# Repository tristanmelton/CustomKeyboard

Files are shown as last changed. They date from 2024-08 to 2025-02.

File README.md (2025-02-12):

### Custom Keyboard and Numpad - Beryl.
I had some problems with Amethyst, namely:
- USB-Micro instead of USB-C
- Wired takes up an already-limited USB slot
- A little tall to type on
- Non-customizable key switches

So for Beryl, I'm proposing:
- USB-C with the nice!nano microcontroller. Also covers wireless with the built-in bluetooth.
- Going to use Kailh switches with low-profile to shorten the height, with hot-swap sockets.  

### Changelog
## 1/25/2025
I did some initial re-organization and copied the v1 to a v2 folder for initial setup. The MCU was replaced with a nice!nano and I'm using hot-swappable Kailh choc switches now.
Board should be laid out and everything - it's been sent off with JLCPCB.

PURCHASED:
- PCB x5 from JLCPCB
- Battery from Amazon
- Kailh hot-swappable sockets x100 from AliExpress
- nice!nano v2 x5 from AliExpress
- JST Connector from Digikey
- Sliding switch from Digikey
- Kailh Low Profile Choc Switches (red) x80 from Typeractive

I only have not ordered Keycaps yet. If you have any suggestions please let me know.

## 2/11/2025
I have updated the PCB with a silly mistake that had GND and VCC swapped on the battery. The software is complete and can be found (https://github.com/tristanmelton/cheapino-zmk-config-single-nicenano). The direct uf2 is also in the Software folder.

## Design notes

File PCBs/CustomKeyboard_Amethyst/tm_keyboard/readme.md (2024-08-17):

# tm_keyboard

tm_keyboard

*A short description of the keyboard/project*

* Keyboard Maintainer: [Tristan Melton](https://github.com/charsmud)
* Hardware Supported: *The PCBs, controllers supported*
* Hardware Availability: *Links to where you can find this hardware*

Make example for this keyboard (after setting up your build environment):

    make tm_keyboard:default

Flashing example for this keyboard:

    make tm_keyboard:default:flash

See the [build environment setup](https://docs.qmk.fm/#/getting_started_build_tools) and the [make instructions](https://docs.qmk.fm/#/getting_started_make_guide) for more information. Brand new to QMK? Start with our [Complete Newbs Guide](https://docs.qmk.fm/#/newbs).

## Bootloader

Enter the bootloader in 3 ways:

* **Bootmagic reset**: Hold down the key at (0,0) in the matrix (usually the top left key or Escape) and plug in the keyboard
* **Physical reset button**: Briefly press the button on the back of the PCB - some may have pads you must short instead
* **Keycode in layout**: Press the key mapped to `QK_BOOT` if it is available

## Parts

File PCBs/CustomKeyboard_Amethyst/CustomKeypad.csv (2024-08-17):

Reference | Value | Datasheet | Footprint | Qty | DNP
C1,C2 | 22p | ~ | Capacitor_SMD:C_0603_1608Metric | 2
C3,C4,C5,C6 | 0.1u | ~ | Capacitor_SMD:C_0603_1608Metric | 4
C7 | 4.7u | ~ | Capacitor_SMD:C_0603_1608Metric | 1
C8 | 1u | ~ | Capacitor_SMD:C_0603_1608Metric | 1
D1,D2,D3,D4,D5,D6,D7,D8,D9,D10,D11,D12,D13,D14,D15,D16,D17,D18,D19,D20,D21,D22,D23,D24,D25,D26,D31,D35,D36,D37,D38,D39,D40,D41,D42,D43,D44,D45,D46,D47,D48,D49,D50,D51,D52,D53,D54,D55,D56,D57,D58,D59,D60,D61,D62,D63,D64,D65,D66,D67,D68,D69,D70,D71,D72,D73,D74,D75,D76,D77,D78,D79,D80,D81 | D | ~ | Diode_SMD:D_0603_1608Metric | 74
J1 | USB_B_Micro | ~ | Connector_USB:USB_Micro-B_Amphenol_10118194_Horizontal | 1
R10,R11 | 10k | ~ | Resistor_SMD:R_0603_1608Metric | 2
R12,R13 | 22 | ~ | Resistor_SMD:R_0603_1608Metric | 2
SW_'1,SW_,1,SW_-1,SW_.1,SW_/1,SW_0,SW_1,SW_2,SW_3,SW_4,SW_5,SW_6,SW_7,SW_8,SW_9,SW_;1,SW_=1,SW_A1,SW_B1,SW_BACK1,SW_C1,SW_CAPS1,SW_D1,SW_E1,SW_ENTER1,SW_ESC1,SW_F1,SW_F2,SW_F3,SW_F4,SW_F5,SW_F6,SW_F7,SW_F8,SW_F9,SW_F10,SW_F11,SW_F12,SW_FKEY1,SW_G1,SW_H1,SW_I1,SW_J1,SW_K1,SW_L1,SW_LALT1,SW_LCTRL1,SW_LSHIFT1,SW_LWIN1,SW_M1,SW_N1,SW_O1,SW_P1,SW_Q1,SW_R1,SW_RALT1,SW_RC1,SW_RCTRL1,SW_RESET1,SW_RSHIFT1,SW_RWIN1,SW_S1,SW_SPACE1,SW_T1,SW_TAB1,SW_TILDE1,SW_U1,SW_V1,SW_W1,SW_X1,SW_Y1,SW_Z1,SW_[1,SW_\1,SW_]1 | SW_Push | ~ | -- mixed values -- | 75
U1 | ATmega32U4-A | http://ww1.microchip.com/downloads/en/DeviceDoc/Atmel-7766-8-bit-AVR-ATmega16U4-32U4_Datasheet.pdf | Package_QFP:TQFP-44_10x10mm_P0.8mm | 1
Y2 | Crystal_GND24 | ~ | Crystal:Crystal_SMD_SeikoEpson_FA238-4Pin_3.2x2.5mm | 1

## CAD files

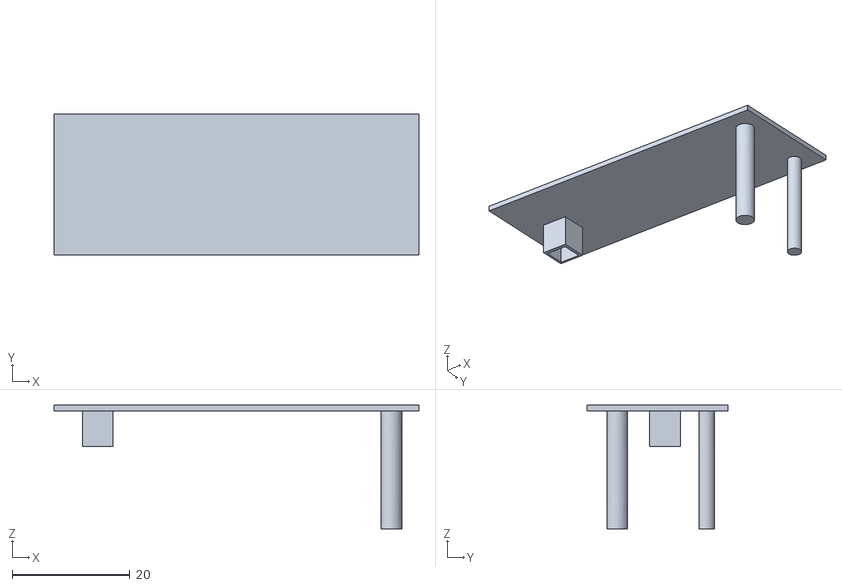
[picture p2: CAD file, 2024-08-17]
PCBs/CustomKeyboard_Amethyst/KeyHolder3.obj
62.0 x 24.0 x 21.0

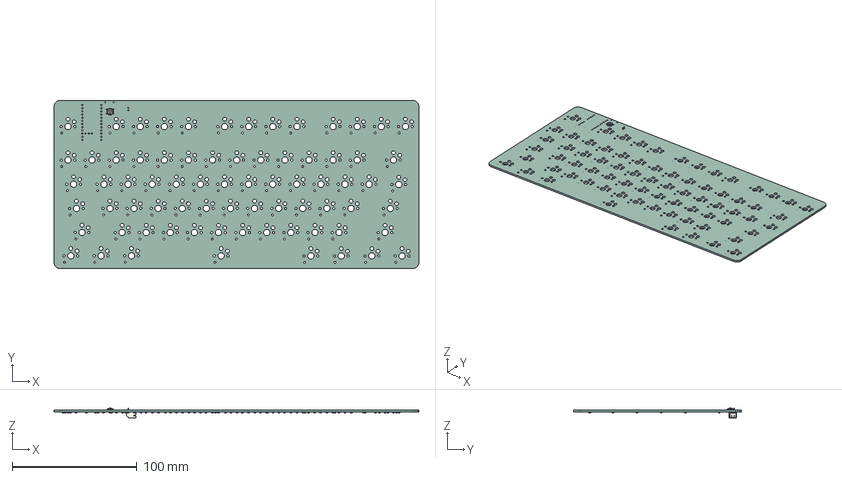
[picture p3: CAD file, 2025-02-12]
PCBs/CustomKeyboard_Beryl/CustomKeyboard.step
293.0 x 135.0 x 8.25 mm
SW_SPST_TL3342
D_0603 x 74
JST_S2B_PH_K
CustomKeyboard_PCB

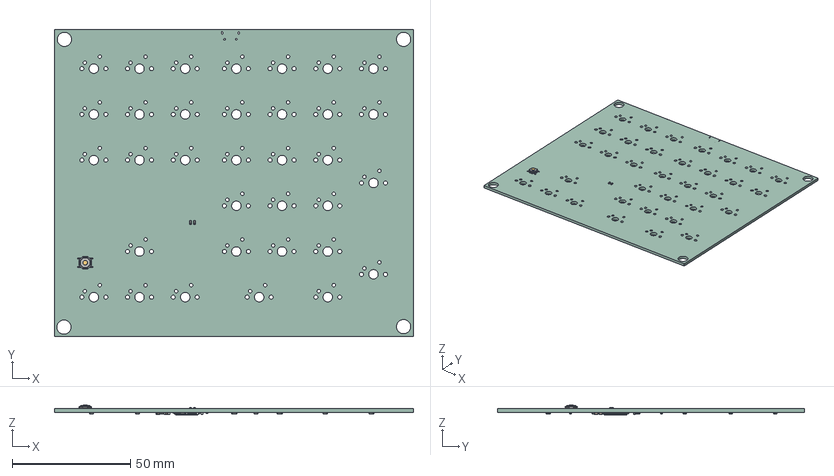
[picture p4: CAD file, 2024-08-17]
PCBs/CustomNumpad_v1/CustomNumpad.step
152.0 x 130.0 x 4.34 mm
R_0603_1608Metric x 4
SW_SPST_TL3342
D_0603 x 34
C_0603_1608Metric x 8
TQFP_44_10x10mm_P08mm
Crystal_SMD_SeikoEpson_FA238-4Pin_3.2x2.5mm
CustomNumpad_PCB

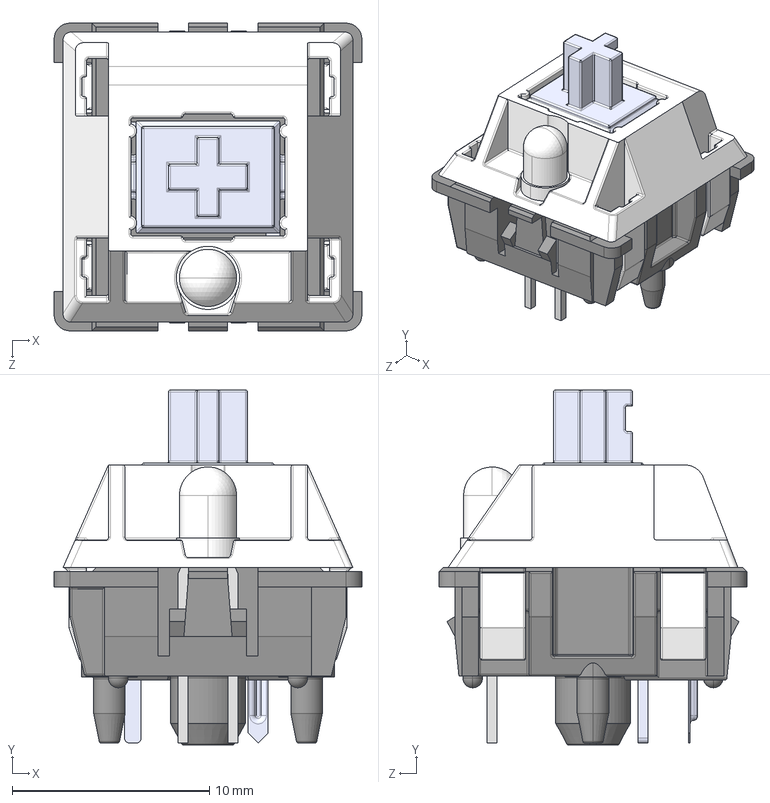
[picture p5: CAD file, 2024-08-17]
Models/Cherry MX.STEP
15.6 x 18.0 x 15.6 mm
Bottom
Pulsador
Top
Pieza5^Cherry MX
Pin1
Pin2
Led 3mm_trans

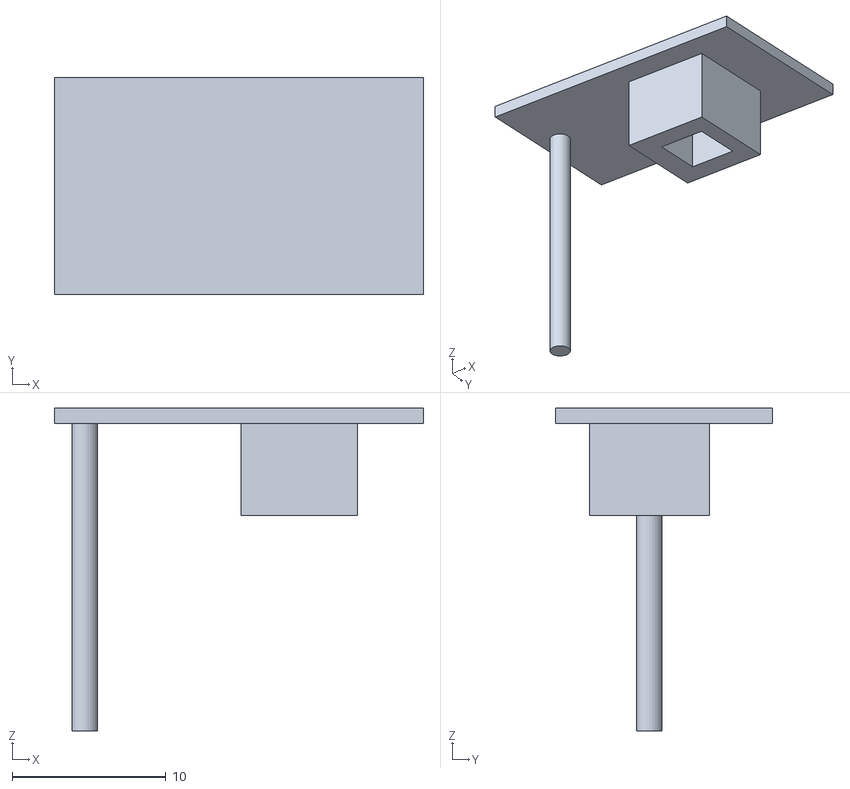
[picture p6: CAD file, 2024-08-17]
PCBs/CustomKeyboard_Amethyst/KeyHolder1.obj
24.0 x 14.1 x 21.0

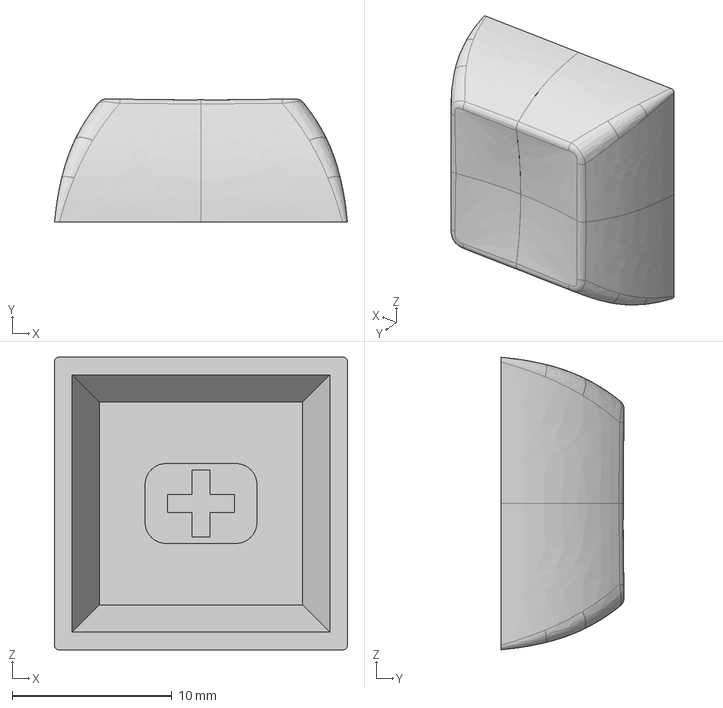
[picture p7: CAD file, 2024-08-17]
Models/DSA_Keycap_CherryMX.step
18.3 x 7.69 x 18.3 mm

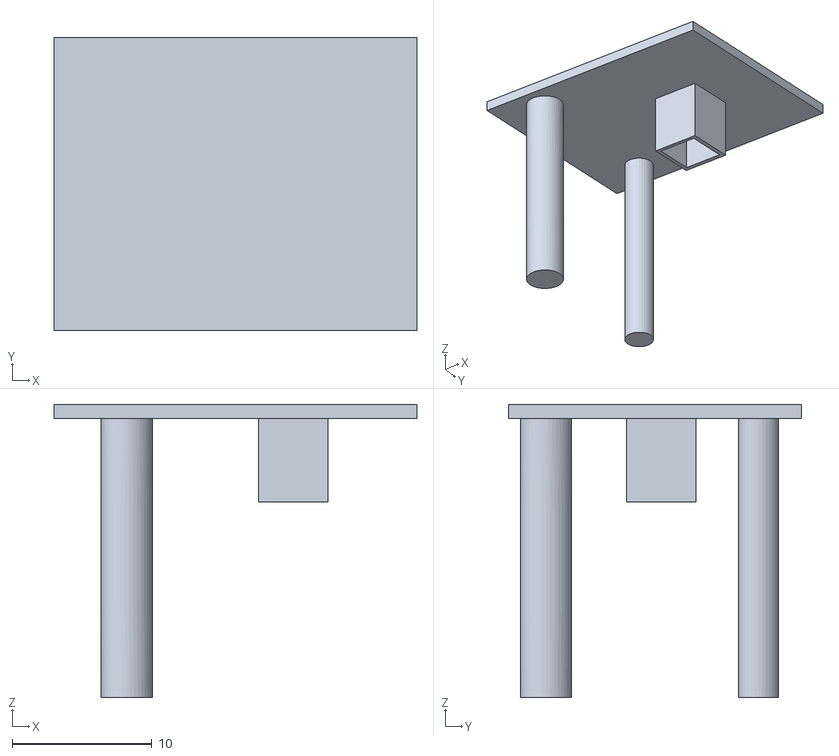
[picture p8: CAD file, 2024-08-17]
PCBs/CustomKeyboard_Amethyst/KeyHolder2.obj
26.0 x 21.0 x 21.0

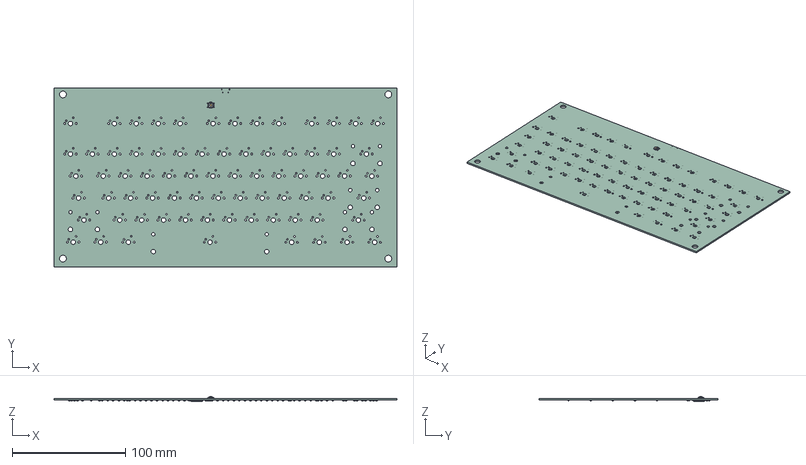
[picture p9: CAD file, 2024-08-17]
PCBs/CustomKeyboard_Amethyst/CustomKeyboard.step
302.5 x 158.3 x 4.34 mm
SW_SPST_TL3342
D_0603 x 74
C_0603_1608Metric x 8
R_0603_1608Metric x 4
TQFP_44_10x10mm_P08mm
Crystal_SMD_SeikoEpson_FA238-4Pin_3.2x2.5mm
CustomKeyboard_PCB

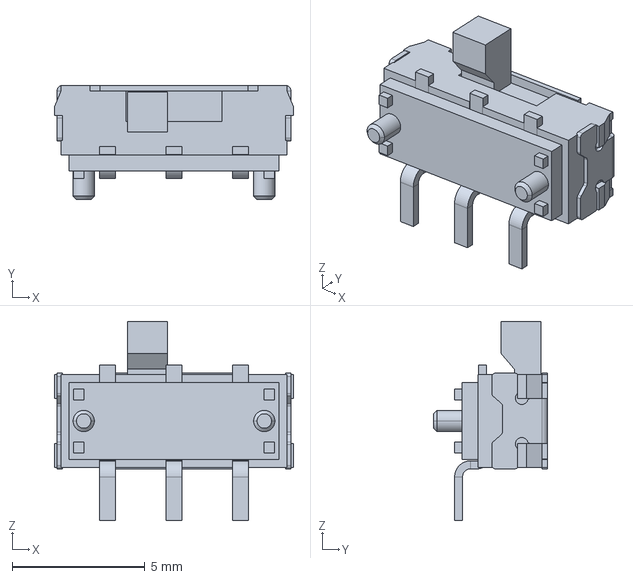
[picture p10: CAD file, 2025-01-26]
Footprints/JS102011SAQN/JS102011SAQN.step
9.00 x 4.30 x 7.50 mm

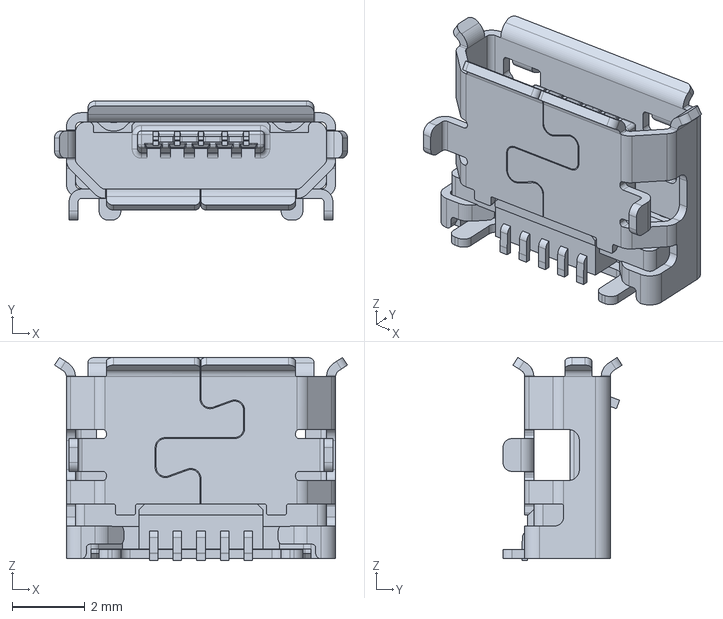
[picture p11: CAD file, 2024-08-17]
Models/10118194c.stp
8.05 x 3.27 x 5.58 mm

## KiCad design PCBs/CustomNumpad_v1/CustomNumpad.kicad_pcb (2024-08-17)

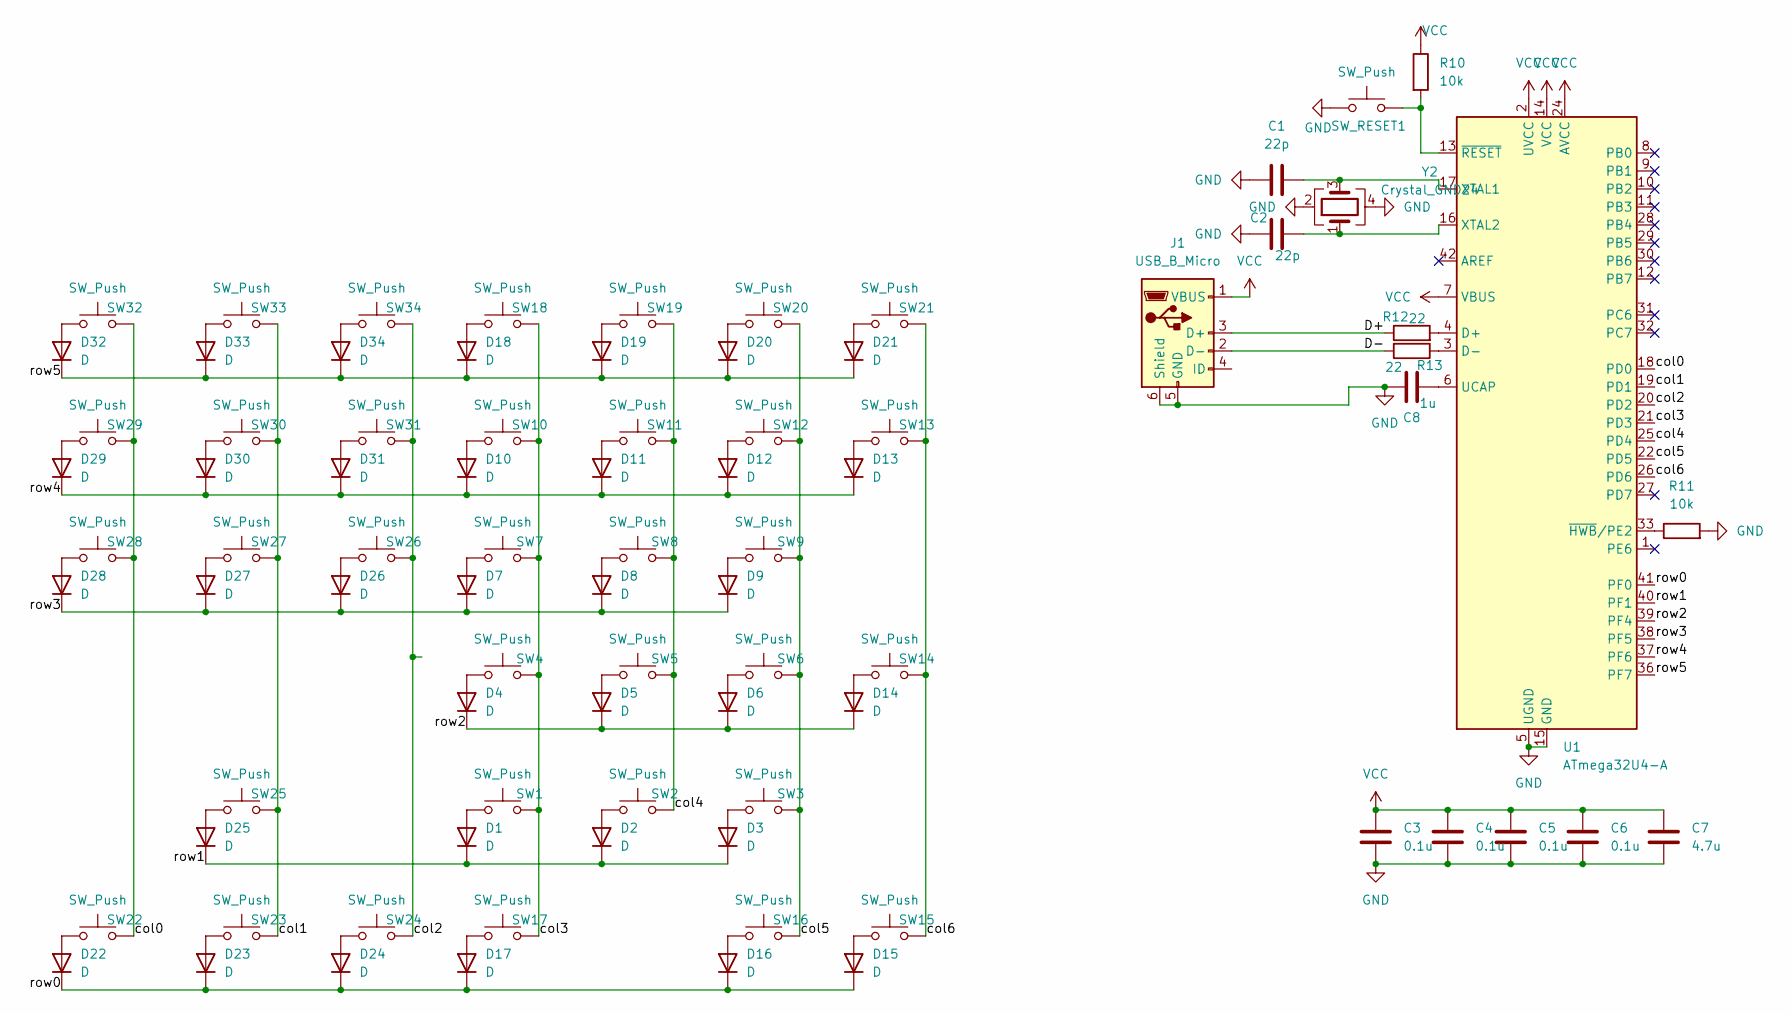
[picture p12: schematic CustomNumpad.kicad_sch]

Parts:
C1, C2: 22p; C_0603_1608Metric
C3, C4, C5, C6: 0.1u; C_0603_1608Metric
C7: 4.7u; C_0603_1608Metric
C8: 1u; C_0603_1608Metric
D1, D2, D3, D4, D5, D6, D7, D8, D9, D10, D11, D12, D13, D14, D15, D16, D17, D18, D19, D20, D21, D22, D23, D24, D25, D26, D27, D28, D29, D30, D31, D32, D33, D34: D; D_0603_1608Metric
J1: USB_B_Micro; USB_Micro-B_Amphenol_10118194_Horizontal
R10, R11: 10k; R_0603_1608Metric
R12, R13: 22; R_0603_1608Metric
SW1, SW2, SW3, SW4, SW5, SW6, SW7, SW8, SW9, SW10, SW11, SW12, SW13, SW16, SW18, SW19, SW20, SW21, SW22, SW23, SW24, SW25, SW26, SW27, SW28, SW29, SW30, SW31, SW32, SW33, SW34: SW_Push; SW_Cherry_MX_PCB_1.00u
SW14, SW15: SW_Push; SW_Cherry_MX_PCB_2.00u_90deg
SW17: SW_Push; SW_Cherry_MX_PCB_2.00u
SW_RESET1: SW_Push; SW_SPST_TL3342
U1: ATmega32U4-A; TQFP-44_10x10mm_P0.8mm
Y2: Crystal_GND24; Crystal_SMD_SeikoEpson_FA238-4Pin_3.2x2.5mm

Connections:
/D+: J1.3 (D+), R12.1
/D-: J1.2 (D-), R13.2
/col0: SW22.2, SW28.2, SW29.2, SW32.2, U1.18 (PD0)
/col1: SW23.2, SW25.2, SW27.2, SW30.2, SW33.2, U1.19 (PD1)
/col2: SW24.2, SW26.2, SW31.2, SW34.2, U1.20 (PD2)
/col3: SW1.2, SW4.2, SW7.2, SW10.2, SW17.2, SW18.2, U1.21 (PD3)
/col4: SW2.2, SW5.2, SW8.2, SW11.2, SW19.2, U1.25 (PD4)
/col5: SW3.2, SW6.2, SW9.2, SW12.2, SW16.2, SW20.2, U1.22 (PD5)
/col6: SW13.2, SW14.2, SW15.2, SW21.2, U1.26 (PD6)
/row0: D15.1 (K), D16.1 (K), D17.1 (K), D22.1 (K), D23.1 (K), D24.1 (K), U1.41 (PF0)
/row1: D1.1 (K), D2.1 (K), D3.1 (K), D25.1 (K), U1.40 (PF1)
/row2: D4.1 (K), D5.1 (K), D6.1 (K), D14.1 (K), U1.39 (PF4)
/row3: D7.1 (K), D8.1 (K), D9.1 (K), D26.1 (K), D27.1 (K), D28.1 (K), U1.38 (PF5)
/row4: D10.1 (K), D11.1 (K), D12.1 (K), D13.1 (K), D29.1 (K), D30.1 (K), D31.1 (K), U1.37 (PF6)
/row5: D18.1 (K), D19.1 (K), D20.1 (K), D21.1 (K), D32.1 (K), D33.1 (K), D34.1 (K), U1.36 (PF7)
GND: C1.1, C2.1, C3.2, C4.2, C5.2, C6.2, C7.2, C8.1, J1.5 (GND), J1.6 (Shield), R11.2, SW_RESET1.1, U1.5 (UGND), U1.15 (GND), U1.23 (GND), U1.35 (GND), U1.43 (GND), Y2.2, Y2.4
unnamed: D1.2 (A), SW1.1
unnamed: D2.2 (A), SW2.1
unnamed: D3.2 (A), SW3.1
unnamed: D4.2 (A), SW4.1
unnamed: D5.2 (A), SW5.1
unnamed: D6.2 (A), SW6.1
unnamed: D7.2 (A), SW7.1
unnamed: D8.2 (A), SW8.1
unnamed: D9.2 (A), SW9.1
unnamed: D10.2 (A), SW10.1
unnamed: D11.2 (A), SW11.1
unnamed: D12.2 (A), SW12.1
unnamed: D13.2 (A), SW13.1
unnamed: D14.2 (A), SW14.1
unnamed: D15.2 (A), SW15.1
unnamed: D16.2 (A), SW16.1
unnamed: D17.2 (A), SW17.1
unnamed: D18.2 (A), SW18.1
unnamed: D19.2 (A), SW19.1
unnamed: D20.2 (A), SW20.1
unnamed: D21.2 (A), SW21.1
unnamed: D22.2 (A), SW22.1
unnamed: D23.2 (A), SW23.1
unnamed: D24.2 (A), SW24.1
unnamed: D25.2 (A), SW25.1
unnamed: D26.2 (A), SW26.1
unnamed: D27.2 (A), SW27.1
unnamed: D28.2 (A), SW28.1
unnamed: D29.2 (A), SW29.1
unnamed: D30.2 (A), SW30.1
unnamed: D31.2 (A), SW31.1
unnamed: D32.2 (A), SW32.1
unnamed: D33.2 (A), SW33.1
unnamed: D34.2 (A), SW34.1
unnamed: R12.2, U1.4 (D+)
unnamed: R13.1, U1.3 (D-)
unnamed: C8.2, U1.6 (UCAP)
unnamed: C1.2, U1.17 (XTAL1), Y2.3
unnamed: C2.2, U1.16 (XTAL2), Y2.1
unnamed: R11.1, U1.33 (~HWB/PE2)
unnamed: R10.2, SW_RESET1.2, U1.13 (~RESET)
VCC: C3.1, C4.1, C5.1, C6.1, C7.1, J1.1 (VBUS), R10.1, U1.2 (UVCC), U1.7 (VBUS), U1.14 (VCC), U1.24 (AVCC), U1.34 (VCC), U1.44 (AVCC)

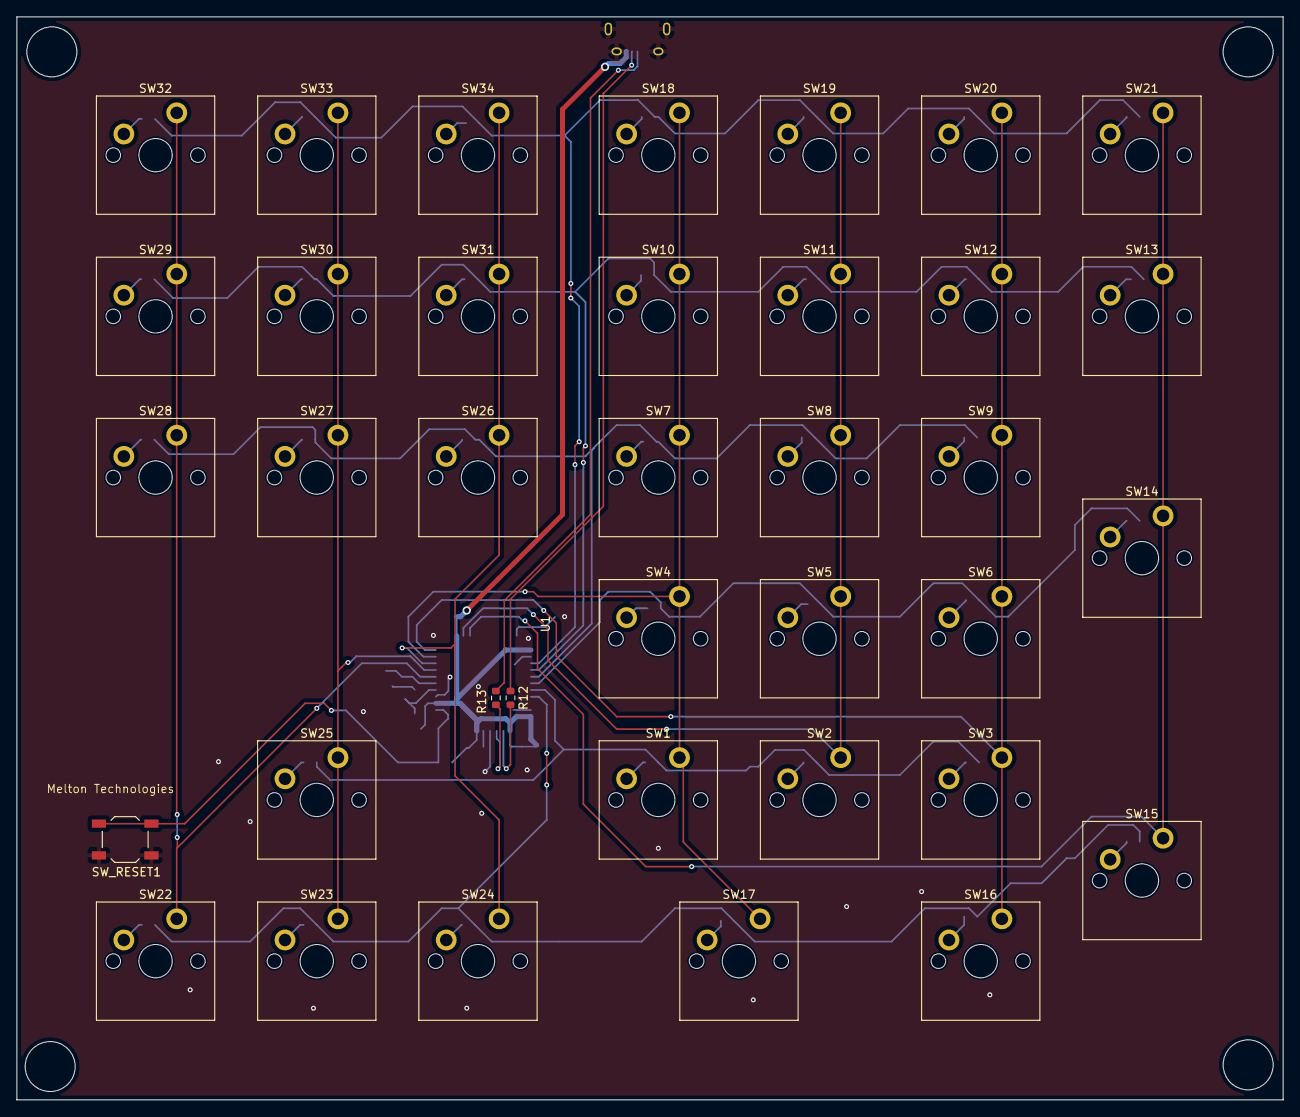
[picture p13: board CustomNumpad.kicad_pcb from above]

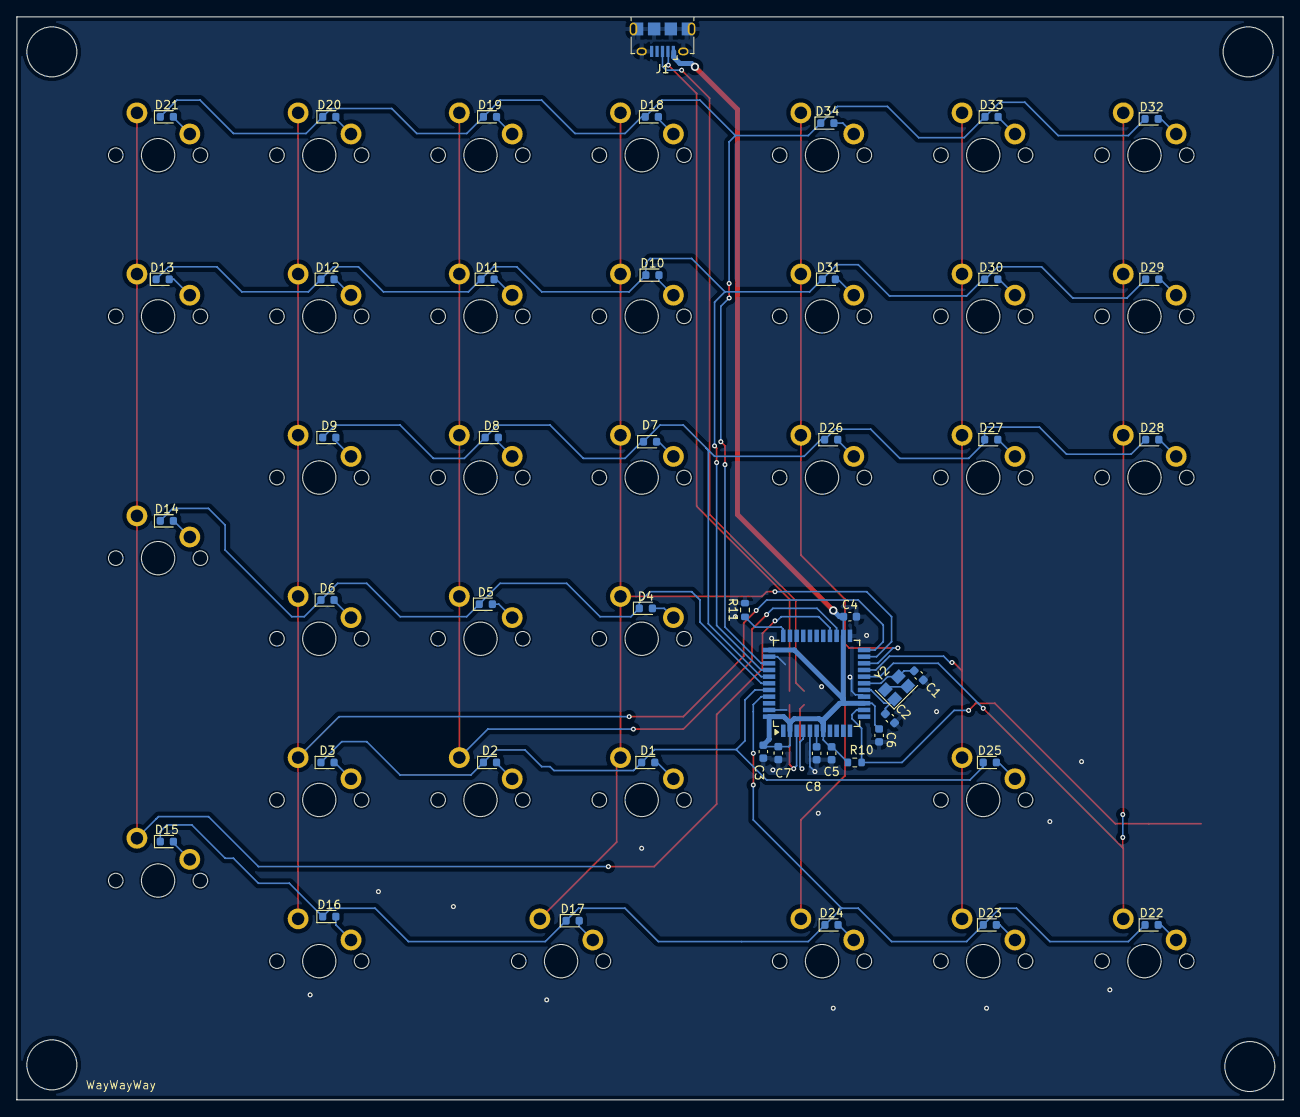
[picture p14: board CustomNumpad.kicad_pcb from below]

Board: 2 copper layers, 152.0 x 130.0 mm, 84 parts (47 on the bottom side), 58 nets.

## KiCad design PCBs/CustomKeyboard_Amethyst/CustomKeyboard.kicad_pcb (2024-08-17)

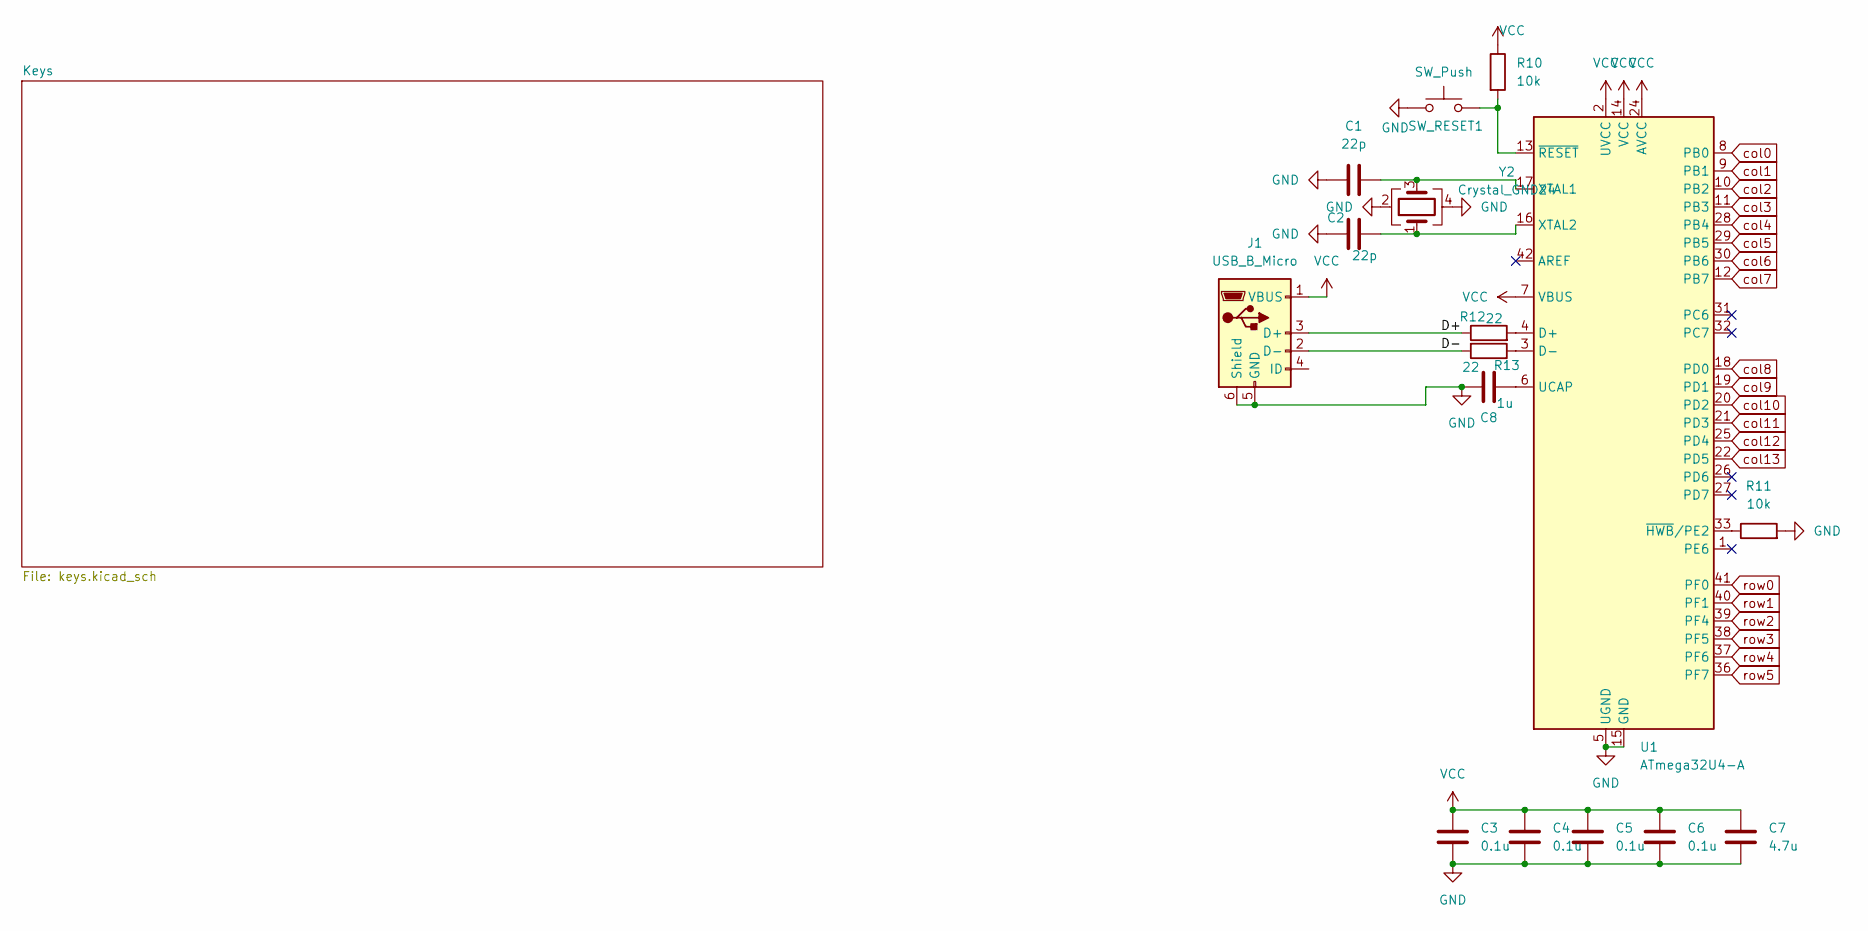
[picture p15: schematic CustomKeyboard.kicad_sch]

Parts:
C1, C2: 22p; C_0603_1608Metric
C3, C4, C5, C6: 0.1u; C_0603_1608Metric
C7: 4.7u; C_0603_1608Metric
C8: 1u; C_0603_1608Metric
J1: USB_B_Micro; USB_Micro-B_Amphenol_10118194_Horizontal
R10, R11: 10k; R_0603_1608Metric
R12, R13: 22; R_0603_1608Metric
SW_RESET1: SW_Push; SW_SPST_TL3342
U1: ATmega32U4-A; TQFP-44_10x10mm_P0.8mm
Y2: Crystal_GND24; Crystal_SMD_SeikoEpson_FA238-4Pin_3.2x2.5mm

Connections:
/D+: J1.3 (D+), R12.1
/D-: J1.2 (D-), R13.2
GND: C1.1, C2.1, C3.2, C4.2, C5.2, C6.2, C7.2, C8.1, J1.5 (GND), J1.6 (Shield), R11.2, SW_RESET1.1, U1.5 (UGND), U1.15 (GND), U1.23 (GND), U1.35 (GND), U1.43 (GND), Y2.2, Y2.4
unnamed: R12.2, U1.4 (D+)
unnamed: R13.1, U1.3 (D-)
unnamed: C8.2, U1.6 (UCAP)
unnamed: C1.2, U1.17 (XTAL1), Y2.3
unnamed: C2.2, U1.16 (XTAL2), Y2.1
unnamed: R11.1, U1.33 (~HWB/PE2)
unnamed: R10.2, SW_RESET1.2, U1.13 (~RESET)
VCC: C3.1, C4.1, C5.1, C6.1, C7.1, J1.1 (VBUS), R10.1, U1.2 (UVCC), U1.7 (VBUS), U1.14 (VCC), U1.24 (AVCC), U1.34 (VCC), U1.44 (AVCC)
col0: U1.8 (PB0); also elsewhere on the board
col1: U1.9 (PB1); also elsewhere on the board
col2: U1.10 (PB2); also elsewhere on the board
col3: U1.11 (PB3); also elsewhere on the board
col4: U1.28 (PB4); also elsewhere on the board
col5: U1.29 (PB5); also elsewhere on the board
col6: U1.30 (PB6); also elsewhere on the board
col7: U1.12 (PB7); also elsewhere on the board
col8: U1.18 (PD0); also elsewhere on the board
col9: U1.19 (PD1); also elsewhere on the board
col10: U1.20 (PD2); also elsewhere on the board
col11: U1.21 (PD3); also elsewhere on the board
col12: U1.25 (PD4); also elsewhere on the board
col13: U1.22 (PD5); also elsewhere on the board
row0: U1.41 (PF0); also elsewhere on the board
row1: U1.40 (PF1); also elsewhere on the board
row2: U1.39 (PF4); also elsewhere on the board
row3: U1.38 (PF5); also elsewhere on the board
row4: U1.37 (PF6); also elsewhere on the board
row5: U1.36 (PF7); also elsewhere on the board

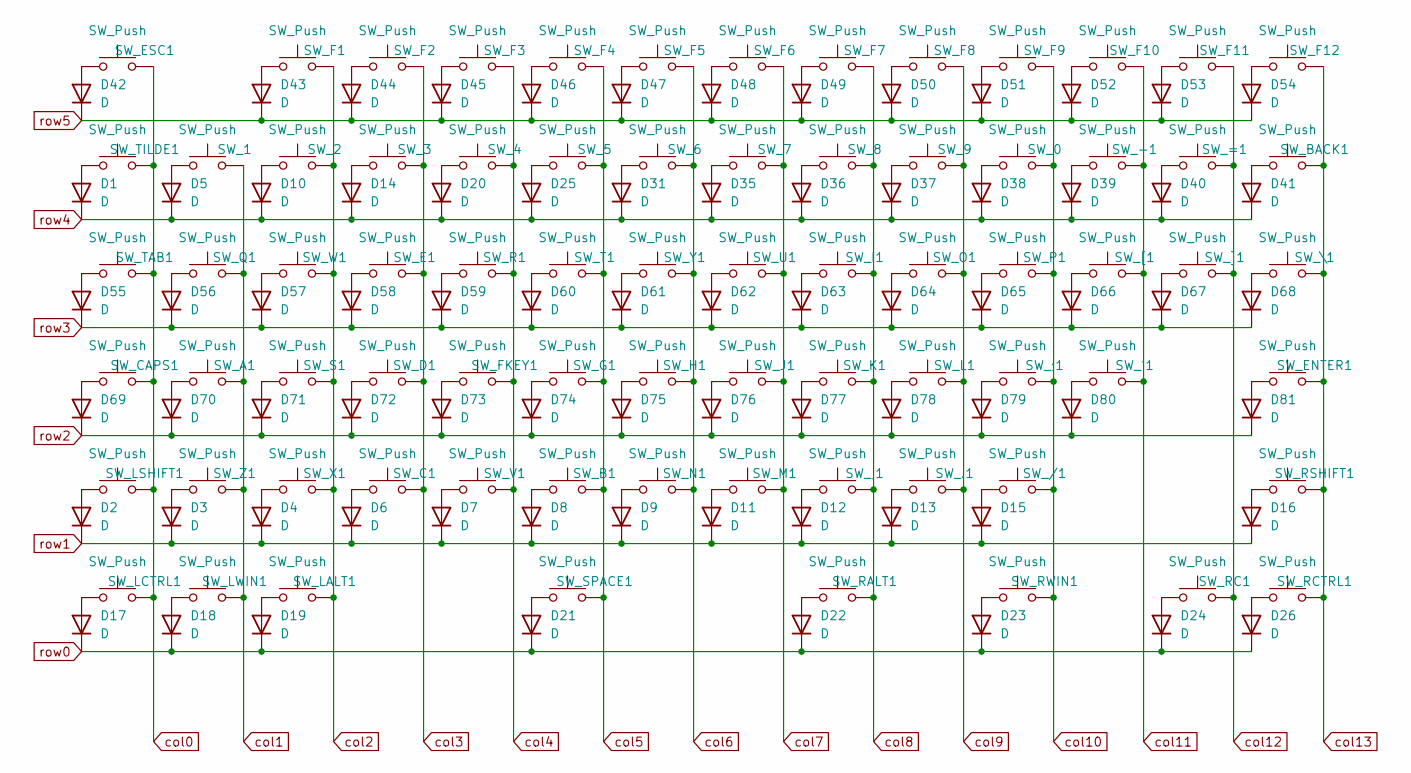
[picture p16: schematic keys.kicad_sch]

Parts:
D1, D2, D3, D4, D5, D6, D7, D8, D9, D10, D11, D12, D13, D14, D15, D16, D17, D18, D19, D20, D21, D22, D23, D24, D25, D26, D31, D35, D36, D37, D38, D39, D40, D41, D42, D43, D44, D45, D46, D47, D48, D49, D50, D51, D52, D53, D54, D55, D56, D57, D58, D59, D60, D61, D62, D63, D64, D65, D66, D67, D68, D69, D70, D71, D72, D73, D74, D75, D76, D77, D78, D79, D80, D81: D; D_0603_1608Metric
SW_0, SW_1, SW_2, SW_3, SW_4, SW_5, SW_6, SW_7, SW_8, SW_9, SW_.1: SW_Push; SW_Cherry_MX_PCB_1.00u
SW_'1: SW_Push; SW_Cherry_MX_PCB_1.00u
SW_,1: SW_Push; SW_Cherry_MX_PCB_1.00u
SW_-1: SW_Push; SW_Cherry_MX_PCB_1.00u
SW_/1: SW_Push; SW_Cherry_MX_PCB_1.00u
SW_;1: SW_Push; SW_Cherry_MX_PCB_1.00u
SW_=1: SW_Push; SW_Cherry_MX_PCB_1.00u
SW_A1: SW_Push; SW_Cherry_MX_PCB_1.00u
SW_B1: SW_Push; SW_Cherry_MX_PCB_1.00u
SW_BACK1: SW_Push; SW_Cherry_MX_2.00u_PCB
SW_C1: SW_Push; SW_Cherry_MX_PCB_1.00u
SW_CAPS1: SW_Push; SW_Cherry_MX_1.75u_PCB
SW_D1: SW_Push; SW_Cherry_MX_PCB_1.00u
SW_E1: SW_Push; SW_Cherry_MX_PCB_1.00u
SW_ENTER1: SW_Push; SW_Cherry_MX_2.25u_PCB
SW_ESC1: SW_Push; SW_Cherry_MX_PCB_1.00u
SW_F1, SW_F2, SW_F3, SW_F4, SW_F5, SW_F6, SW_F7, SW_F8, SW_F9, SW_F10, SW_F11, SW_F12: SW_Push; SW_Cherry_MX_PCB_1.00u
SW_FKEY1: SW_Push; SW_Cherry_MX_PCB_1.00u
SW_G1: SW_Push; SW_Cherry_MX_PCB_1.00u
SW_H1: SW_Push; SW_Cherry_MX_PCB_1.00u
SW_I1: SW_Push; SW_Cherry_MX_PCB_1.00u
SW_J1: SW_Push; SW_Cherry_MX_PCB_1.00u
SW_K1: SW_Push; SW_Cherry_MX_PCB_1.00u
SW_L1: SW_Push; SW_Cherry_MX_PCB_1.00u
SW_LALT1: SW_Push; SW_Cherry_MX_1.25u_PCB
SW_LCTRL1: SW_Push; SW_Cherry_MX_1.25u_PCB
SW_LSHIFT1: SW_Push; SW_Cherry_MX_2.25u_PCB
SW_LWIN1: SW_Push; SW_Cherry_MX_1.25u_PCB
SW_M1: SW_Push; SW_Cherry_MX_PCB_1.00u
SW_N1: SW_Push; SW_Cherry_MX_PCB_1.00u
SW_O1: SW_Push; SW_Cherry_MX_PCB_1.00u
SW_P1: SW_Push; SW_Cherry_MX_PCB_1.00u
SW_Q1: SW_Push; SW_Cherry_MX_PCB_1.00u
SW_R1: SW_Push; SW_Cherry_MX_PCB_1.00u
SW_RALT1: SW_Push; SW_Cherry_MX_1.25u_PCB
SW_RC1: SW_Push; SW_Cherry_MX_1.25u_PCB
SW_RCTRL1: SW_Push; SW_Cherry_MX_1.25u_PCB
SW_RSHIFT1: SW_Push; SW_Cherry_MX_2.75u_PCB
SW_RWIN1: SW_Push; SW_Cherry_MX_1.25u_PCB
SW_S1: SW_Push; SW_Cherry_MX_PCB_1.00u
SW_SPACE1: SW_Push; SW_Cherry_MX_6.25u_PCB
SW_T1: SW_Push; SW_Cherry_MX_PCB_1.00u
SW_TAB1: SW_Push; SW_Cherry_MX_1.50u_PCB
SW_TILDE1: SW_Push; SW_Cherry_MX_PCB_1.00u
SW_U1: SW_Push; SW_Cherry_MX_PCB_1.00u
SW_V1: SW_Push; SW_Cherry_MX_PCB_1.00u
SW_W1: SW_Push; SW_Cherry_MX_PCB_1.00u
SW_X1: SW_Push; SW_Cherry_MX_PCB_1.00u
SW_Y1: SW_Push; SW_Cherry_MX_PCB_1.00u
SW_Z1: SW_Push; SW_Cherry_MX_PCB_1.00u
SW_[1: SW_Push; SW_Cherry_MX_PCB_1.00u
SW_\1: SW_Push; SW_Cherry_MX_1.50u_PCB
SW_]1: SW_Push; SW_Cherry_MX_PCB_1.00u

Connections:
unnamed: D1.2 (A), SW_TILDE1.1
unnamed: D2.2 (A), SW_LSHIFT1.1
unnamed: D3.2 (A), SW_Z1.1
unnamed: D4.2 (A), SW_X1.1
unnamed: D5.2 (A), SW_1.1
unnamed: D6.2 (A), SW_C1.1
unnamed: D7.2 (A), SW_V1.1
unnamed: D8.2 (A), SW_B1.1
unnamed: D9.2 (A), SW_N1.1
unnamed: D10.2 (A), SW_2.1
unnamed: D11.2 (A), SW_M1.1
unnamed: D12.2 (A), SW_,1.1
unnamed: D13.2 (A), SW_.1.1
unnamed: D14.2 (A), SW_3.1
unnamed: D15.2 (A), SW_/1.1
unnamed: D16.2 (A), SW_RSHIFT1.1
unnamed: D17.2 (A), SW_LCTRL1.1
unnamed: D18.2 (A), SW_LWIN1.1
unnamed: D19.2 (A), SW_LALT1.1
unnamed: D20.2 (A), SW_4.1
unnamed: D21.2 (A), SW_SPACE1.1
unnamed: D22.2 (A), SW_RALT1.1
unnamed: D23.2 (A), SW_RWIN1.1
unnamed: D24.2 (A), SW_RC1.1
unnamed: D25.2 (A), SW_5.1
unnamed: D26.2 (A), SW_RCTRL1.1
unnamed: D31.2 (A), SW_6.1
unnamed: D35.2 (A), SW_7.1
unnamed: D36.2 (A), SW_8.1
unnamed: D37.2 (A), SW_9.1
unnamed: D38.2 (A), SW_0.1
unnamed: D39.2 (A), SW_-1.1
unnamed: D40.2 (A), SW_=1.1
unnamed: D41.2 (A), SW_BACK1.1
unnamed: D42.2 (A), SW_ESC1.1
unnamed: D43.2 (A), SW_F1.1
unnamed: D44.2 (A), SW_F2.1
unnamed: D45.2 (A), SW_F3.1
unnamed: D46.2 (A), SW_F4.1
unnamed: D47.2 (A), SW_F5.1
unnamed: D48.2 (A), SW_F6.1
unnamed: D49.2 (A), SW_F7.1
unnamed: D50.2 (A), SW_F8.1
unnamed: D51.2 (A), SW_F9.1
unnamed: D52.2 (A), SW_F10.1
unnamed: D53.2 (A), SW_F11.1
unnamed: D54.2 (A), SW_F12.1
unnamed: D55.2 (A), SW_TAB1.1
unnamed: D56.2 (A), SW_Q1.1
unnamed: D57.2 (A), SW_W1.1
unnamed: D58.2 (A), SW_E1.1
unnamed: D59.2 (A), SW_R1.1
unnamed: D60.2 (A), SW_T1.1
unnamed: D61.2 (A), SW_Y1.1
unnamed: D62.2 (A), SW_U1.1
unnamed: D63.2 (A), SW_I1.1
unnamed: D64.2 (A), SW_O1.1
unnamed: D65.2 (A), SW_P1.1
unnamed: D66.2 (A), SW_[1.1
unnamed: D67.2 (A), SW_]1.1
unnamed: D68.2 (A), SW_\1.1
unnamed: D69.2 (A), SW_CAPS1.1
unnamed: D70.2 (A), SW_A1.1
unnamed: D71.2 (A), SW_S1.1
unnamed: D72.2 (A), SW_D1.1
unnamed: D73.2 (A), SW_FKEY1.1
unnamed: D74.2 (A), SW_G1.1
unnamed: D75.2 (A), SW_H1.1
unnamed: D76.2 (A), SW_J1.1
unnamed: D77.2 (A), SW_K1.1
unnamed: D78.2 (A), SW_L1.1
unnamed: D79.2 (A), SW_;1.1
unnamed: D80.2 (A), SW_'1.1
unnamed: D81.2 (A), SW_ENTER1.1
col0: SW_CAPS1.2, SW_ESC1.2, SW_LCTRL1.2, SW_LSHIFT1.2, SW_TAB1.2, SW_TILDE1.2; also elsewhere on the board
col1: SW_1.2, SW_A1.2, SW_LWIN1.2, SW_Q1.2, SW_Z1.2; also elsewhere on the board
col2: SW_2.2, SW_F1.2, SW_LALT1.2, SW_S1.2, SW_W1.2, SW_X1.2; also elsewhere on the board
col3: SW_3.2, SW_C1.2, SW_D1.2, SW_E1.2, SW_F2.2; also elsewhere on the board
col4: SW_4.2, SW_F3.2, SW_FKEY1.2, SW_R1.2, SW_V1.2; also elsewhere on the board
col5: SW_5.2, SW_B1.2, SW_F4.2, SW_G1.2, SW_SPACE1.2, SW_T1.2; also elsewhere on the board
col6: SW_6.2, SW_F5.2, SW_H1.2, SW_N1.2, SW_Y1.2; also elsewhere on the board
col7: SW_7.2, SW_F6.2, SW_J1.2, SW_M1.2, SW_U1.2; also elsewhere on the board
col8: SW_8.2, SW_,1.2, SW_F7.2, SW_I1.2, SW_K1.2, SW_RALT1.2; also elsewhere on the board
col9: SW_9.2, SW_.1.2, SW_F8.2, SW_L1.2, SW_O1.2; also elsewhere on the board
col10: SW_0.2, SW_/1.2, SW_;1.2, SW_F9.2, SW_P1.2, SW_RWIN1.2; also elsewhere on the board
col11: SW_'1.2, SW_-1.2, SW_F10.2, SW_[1.2; also elsewhere on the board
col12: SW_=1.2, SW_F11.2, SW_RC1.2, SW_]1.2; also elsewhere on the board
col13: SW_BACK1.2, SW_ENTER1.2, SW_F12.2, SW_RCTRL1.2, SW_RSHIFT1.2, SW_\1.2; also elsewhere on the board
row0: D17.1 (K), D18.1 (K), D19.1 (K), D21.1 (K), D22.1 (K), D23.1 (K), D24.1 (K), D26.1 (K); also elsewhere on the board
row1: D2.1 (K), D3.1 (K), D4.1 (K), D6.1 (K), D7.1 (K), D8.1 (K), D9.1 (K), D11.1 (K), D12.1 (K), D13.1 (K), D15.1 (K), D16.1 (K); also elsewhere on the board
row2: D69.1 (K), D70.1 (K), D71.1 (K), D72.1 (K), D73.1 (K), D74.1 (K), D75.1 (K), D76.1 (K), D77.1 (K), D78.1 (K), D79.1 (K), D80.1 (K), D81.1 (K); also elsewhere on the board
row3: D55.1 (K), D56.1 (K), D57.1 (K), D58.1 (K), D59.1 (K), D60.1 (K), D61.1 (K), D62.1 (K), D63.1 (K), D64.1 (K), D65.1 (K), D66.1 (K), D67.1 (K), D68.1 (K); also elsewhere on the board
row4: D1.1 (K), D5.1 (K), D10.1 (K), D14.1 (K), D20.1 (K), D25.1 (K), D31.1 (K), D35.1 (K), D36.1 (K), D37.1 (K), D38.1 (K), D39.1 (K), D40.1 (K), D41.1 (K); also elsewhere on the board
row5: D42.1 (K), D43.1 (K), D44.1 (K), D45.1 (K), D46.1 (K), D47.1 (K), D48.1 (K), D49.1 (K), D50.1 (K), D51.1 (K), D52.1 (K), D53.1 (K), D54.1 (K); also elsewhere on the board

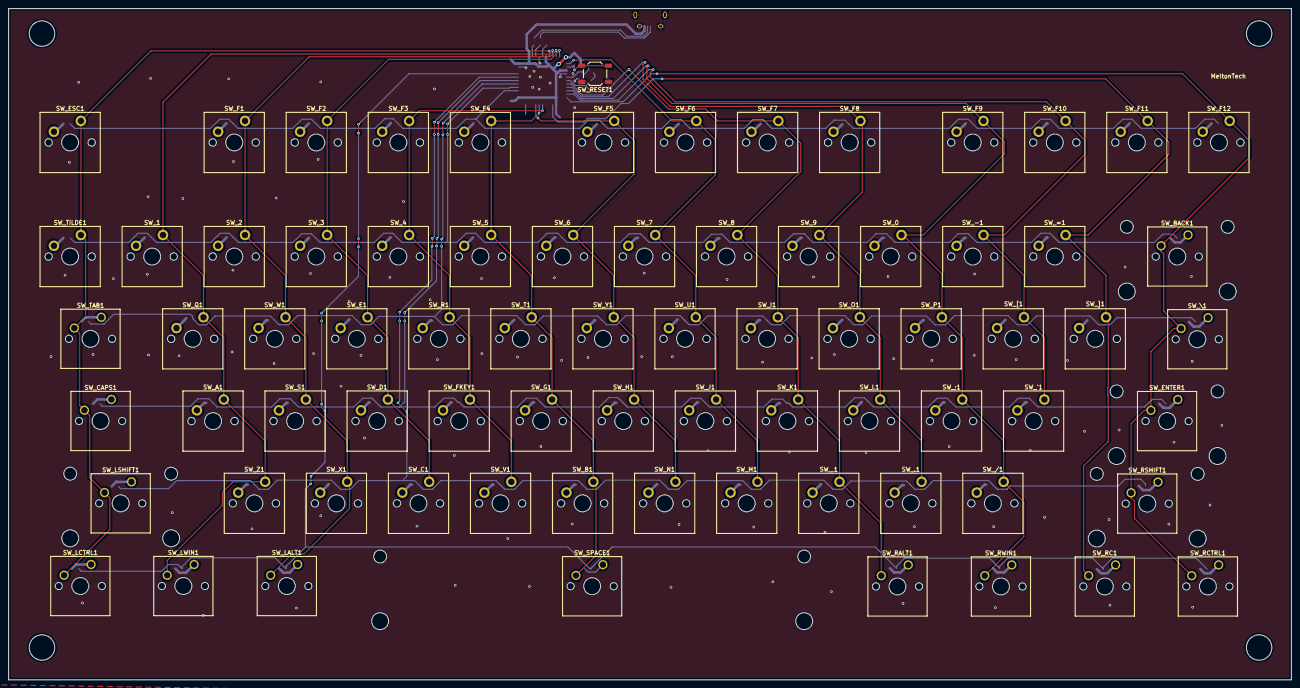
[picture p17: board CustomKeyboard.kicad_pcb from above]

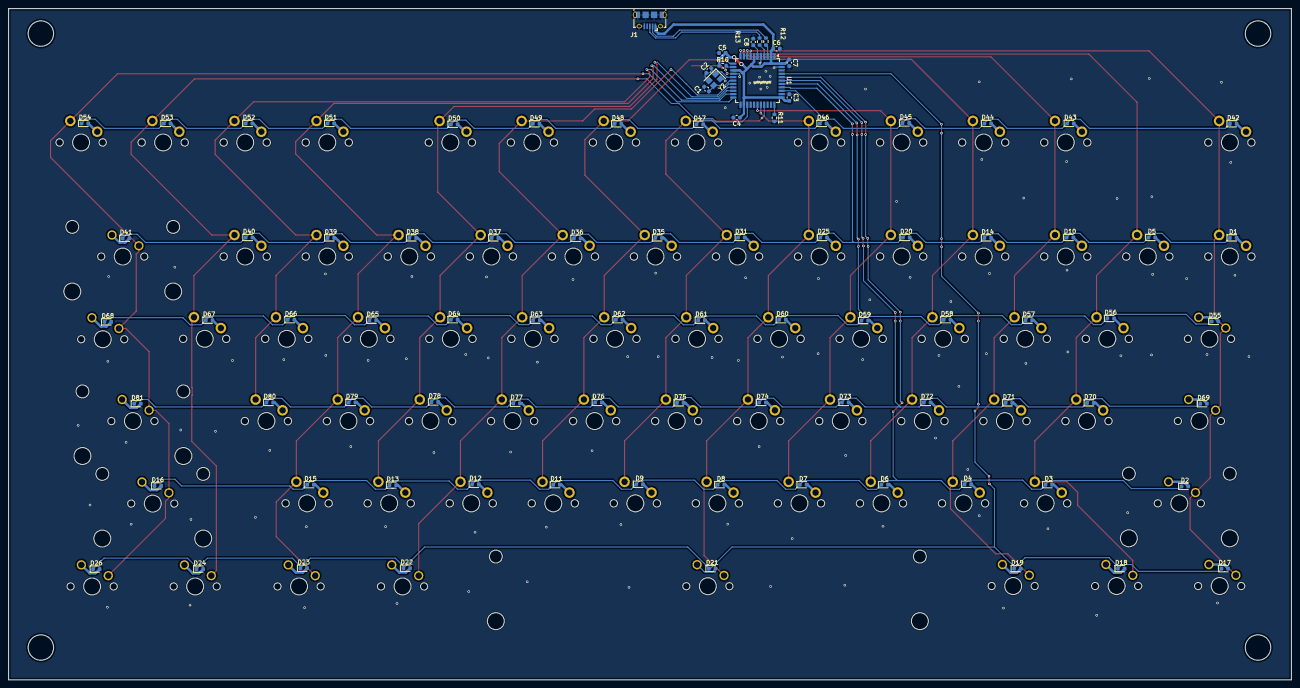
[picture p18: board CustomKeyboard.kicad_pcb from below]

Board: 2 copper layers, 302.5 x 158.3 mm, 164 parts (89 on the bottom side), 105 nets.

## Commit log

2024-08-17 Initial Commit. Will add the 3D model for the case later.
    [10118194c.stp, Cherry MX.STEP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]
2025-01-26 Beginning work on Keyboard-Beryl.
    [10118194c.stp, Cherry MX.STEP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]
2025-02-12 Completed Build!
    [CustomKeyboard.kicad_sch, CustomKeyboard.step]
